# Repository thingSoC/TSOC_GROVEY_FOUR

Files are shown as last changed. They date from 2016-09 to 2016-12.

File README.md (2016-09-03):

# TSOC_GROVEY_FOUR

The **TSOC_GROVEY_FOUR** allows you to connect [thingSoC](http://thingsoc.github.io/), [Mikrobus](http://www.mikroe.com/mikrobus/), 
and/or [Grove System](http://www.seeedstudio.com/blog/2016/03/09/tutorial-intro-to-grove-connectors-for-arduinoraspberry-pi-projects/) 
Modules all at the same time, either standalone, or with any Processor or Radio module.
This gives you maximum flexiblity for parts selection and reuse. 

The **TSOC_GROVEY_FOUR** uses a Cypress Semiconductor PsoC4, a CY8C4245PVI-482 model in a 28 pin TSSOP package, for easy hand soldering.

The thingSoC "Grovey Series" was designed as "Everyday Electronics", a no-frills, low cost, approach to modular embedded product design.
thingSoC boards are similar in size to most break-out-boards (BOBs), but feature a standardized stacking pinout, as well as an I2C metadata store (EEPROM)
to indicate what peripherals are installed.

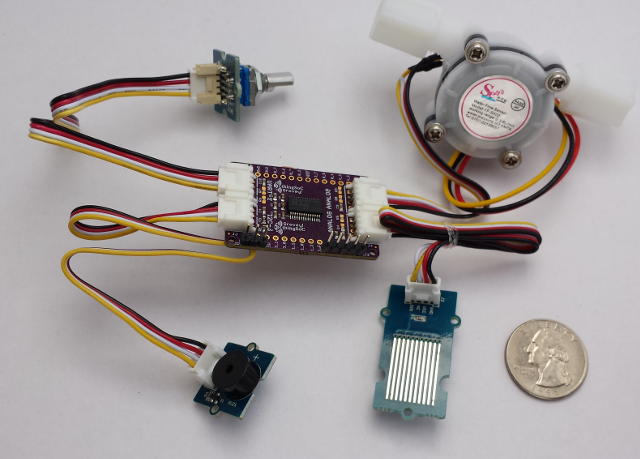
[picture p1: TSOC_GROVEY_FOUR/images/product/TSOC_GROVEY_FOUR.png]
thingSoC TSOC_GROVEY_FOUR
[TSOC_GROVEY_FOUR](https://github.com/thingSoC/TSOC_GROVEY_FOUR)

**thingSoC Reference Designs** are example thingSoC implementations that implement
various reference and testing circuits for demonstrating the use of the thingSoC libraries.
These reference designs can serve as starting templates for user designs.

---------------------------------------

## TSOC_GROVEY_FOUR Grove Application Pictures

Add the thingSoC GROVEY_WIFI for wireless measurement and control. This example uses a knob (potentiometer) for input, a water level sensor, a buzzer,  and a pump.
If the system detects water in the basement, it can sound the buzzer and start the pump (as an example...) 

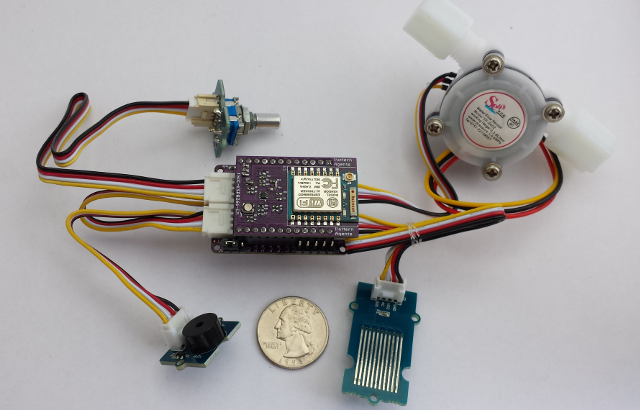
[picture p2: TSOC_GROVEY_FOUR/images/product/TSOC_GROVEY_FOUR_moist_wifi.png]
thingSoC TSOC_GROVEY_FOUR
[*TSOC_GROVEY_FOUR*](https://github.com/thingSoC/TSOC_GROVEY_FOUR)

Or use a soil moisture sensor to control when your plants get watered. Add an OLED display to get you measusements.

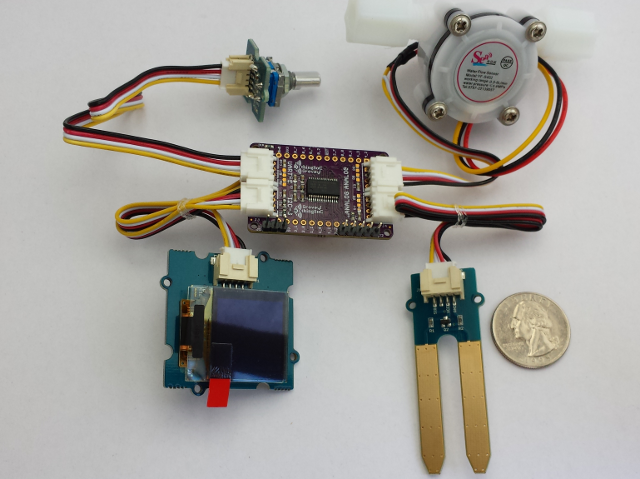
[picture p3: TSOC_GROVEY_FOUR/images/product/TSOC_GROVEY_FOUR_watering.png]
thingSoC TSOC_GROVEY_FOUR
[*TSOC_GROVEY_FOUR*](https://github.com/thingSoC/TSOC_GROVEY_FOUR)

---------------------------------------

## TSOC_GROVEY_FOUR Mikrobus "Click" Application Pictures

The **TSOC_GROVEY_FOUR** is also compatibile with most [Mikrobus](http://www.mikroe.com/mikrobus/) "Click" peripherals.
now you can mix-and-match Click System peripherals with Grove System peripherals at the same time!

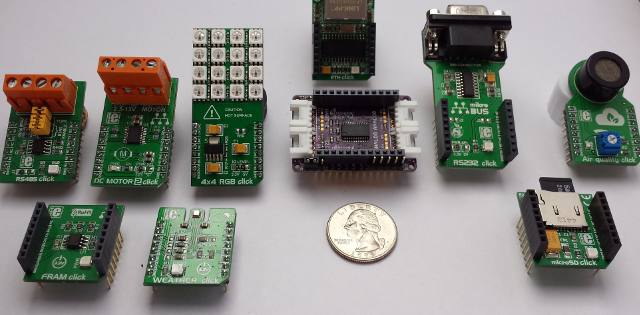
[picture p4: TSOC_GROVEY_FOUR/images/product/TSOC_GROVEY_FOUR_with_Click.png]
thingSoC TSOC_GROVEY_FOUR
[*TSOC_GROVEY_FOUR*](https://github.com/thingSoC/TSOC_GROVEY_FOUR)

---------------------------------------

## TSOC_GROVEY_FOUR Arduino Sketch Examples

Under the "examples" directory are several Arduino IDE examples for using the TSOC_GROVEY_FOUR board with Arduino IDE.
Using the Arduino "Wire" library for I2C communications, or Arduino "Serial" library for UART communications,
it is simple to control the TSOC_GROVEY_FOUR. Although the TSOC_GROVEY_FOUR uses programmable hardware, the device comes
preprogrammed to act as either an I2C I/O Expander, or a UART command line controlled peripheral. T

```c
 
 coming...

```

---------------------------------------
## TSOC_GROVEY_FOUR Programming

The included UART bootloader allows you to reprogram the PSoC with your own programs,
or to chose from a variety of "recipe" programs available for many applications.

You can reprogram the board using any FTDI USB to UART, or any Grove UART adapter :

In order to reprogram the Cypress PSoC4 device, you will need to download and install the PSoC Creator tool, which includes a serial bootloader host application.

Select Tools -> Bootloader Host 

Then select the hex (cyacd) file that you wish to program, and the COM: port of your device. Proess the "Upload" button to reflash teh device.

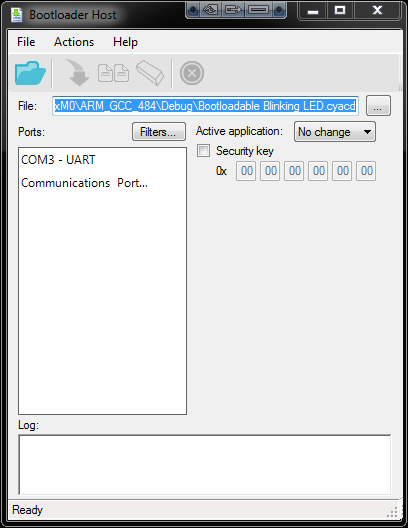
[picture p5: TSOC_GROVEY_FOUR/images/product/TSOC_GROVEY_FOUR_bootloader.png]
thingSoC TSOC_GROVEY_FOUR
[PSoC Creator Bootloader Host](https://github.com/thingSoC/TSOC_GROVEY_FOUR)

---------------------------------------
## Other Applications

The TSOC_GROVEY_FOUR can also drive other devices, such as Servos, Motors, Relays and more.

---------------------------------------

## TSOC_GROVEY_FOUR Status <a name="TSOC_GROVEY_FOUR_status"/>

**08/15/2016:** 
Revision 1.4 - Initial Layout 

**08/20/2016:**
Revision 2.0 - Alpha version

**09/02/2016:**
Revision 3.0 - (WIP) add FTDI, JTAG, and 3.3V/5V voltage select jumper

---------------------------------------
## TSOC_GROVEY_FOUR Model Images

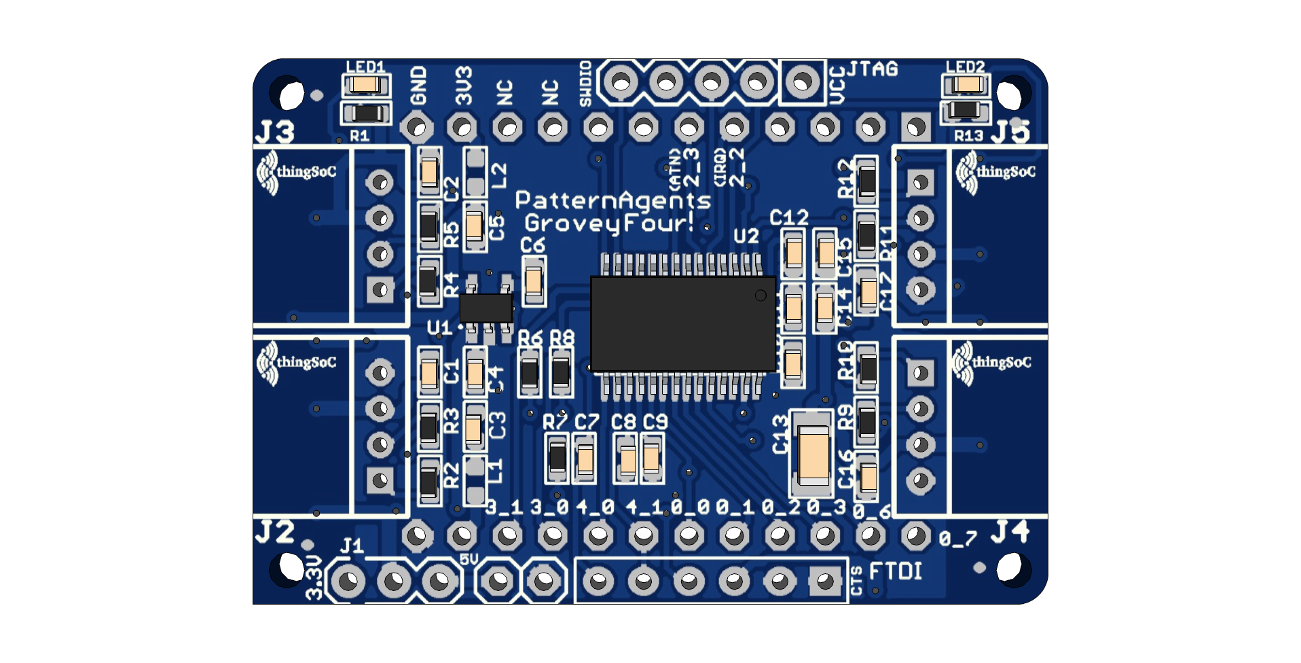
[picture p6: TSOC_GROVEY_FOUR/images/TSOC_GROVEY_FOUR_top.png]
thingSoC TSOC_GROVEY_FOUR
[TSOC_GROVEY_FOUR](https://github.com/thingSoC/TSOC_GROVEY_FOUR)

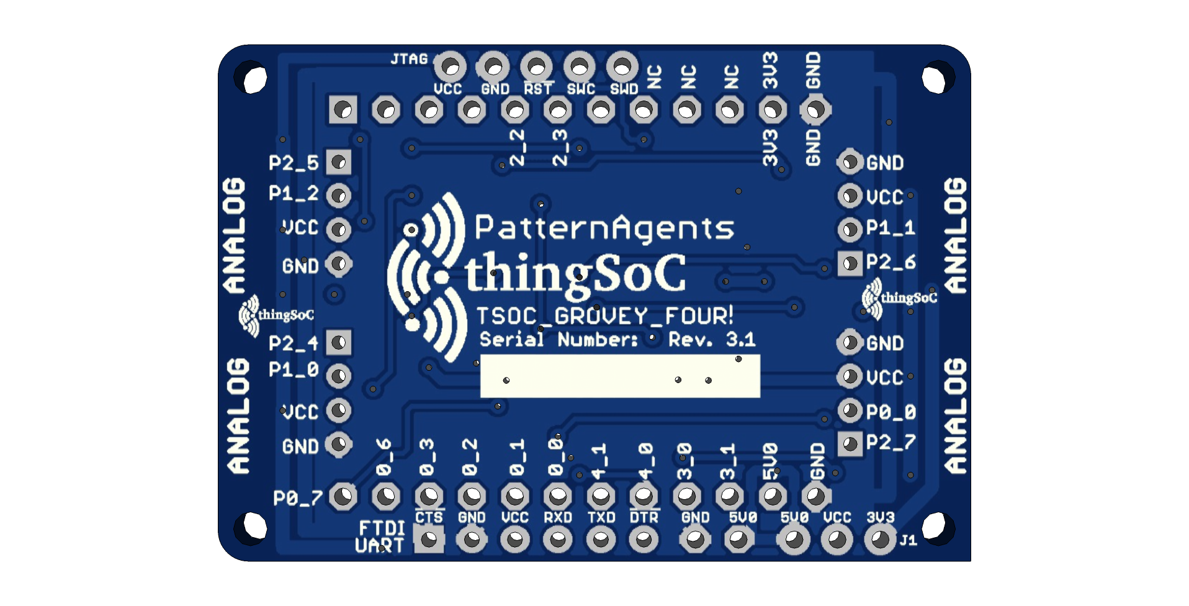
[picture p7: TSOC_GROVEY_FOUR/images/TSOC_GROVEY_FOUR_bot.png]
thingSoC TSOC_GROVEY_FOUR
[TSOC_GROVEY_FOUR](https://github.com/thingSoC/TSOC_GROVEY_FOUR)

---------------------------------------

## TSOC_GROVEY_FOUR Documentation Index <a name="TSOC_GROVEY_FOUR_documentation_index"/>

[TSOC_GROVEY_FOUR Project](http://thingsoc.github.io/projects/TSOC_GROVEY_FOUR.html)

[TSOC_GROVEY_FOUR Hardware](https://github.com/thingSoC/TSOC_GROVEY_FOUR/tree/master/TSOC_GROVEY_FOUR/hardware)

---------------------------------------

## thingSoC Documentation Index <a name="thingSoC_documentation_index"/>

[thingSoC Organization Website](http://thingSoC.github.io)

[thingSoC FAQ - Frequently Asked Questions](http://thingsoc.github.io/support/faq.html)

---------------------------------------

[thingSoC 
*thingSoC*](http://thingsoc.github.io)

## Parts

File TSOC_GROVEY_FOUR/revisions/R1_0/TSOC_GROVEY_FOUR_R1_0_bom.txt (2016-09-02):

Partlist exported from U:/PatternAgents/eagle/TSOC_Modules/TSOC_GROVEY/TSOC_GROVEY/TSOC_GROVEY.sch at 8/27/2016 3:07:50 PM  Revision 2.0                                                                                  

Qty Value             Device                          Package           Parts                       Description 
1   JMP               JMP-2-PTH                       JMP-2-PTH-2.54    J1                          Jumper
1   Red               LED0603                         LED-0603          D1                          LEDs
3   0.1uF             CAP0603-CAP                     0603-CAP          C3, C6, C8                  Capacitor
1   10K               RESISTOR_SFE0603-RES            0603-RES          R2                          Resistor
1   1K                RESISTOR_SFE0603-RES            0603-RES          R10                         Resistor                                                                  
7   1uF               CAP0603-CAP                     0603-CAP          C1, C2, C4, C5, C7, C9, C10 Capacitor
6   2k2               RESISTOR0603-RES                0603-RES          R1, R3, R4, R5, R8, R9      Resistor                                                                  
4   4P-2.0-90D        GROVE-CONNECTOR-DIP-90D(4P-2.0) HW4-2.0-90D       J3, J4, J5, J6              320110034
1   CY8C4245PVI-482   CY8C4245PVI-482                 SSOP28            U1                          Cypress PSoC® 4
2   DNP               RESISTOR0603-RES                0603-RES          R6, R7                      Resistor                                                                  
1   JTAG-ISSPMIN      JTAG-ISSPMIN                    PSOC_JTAG_MINSILK J2                          JTAG-ISSP Connector

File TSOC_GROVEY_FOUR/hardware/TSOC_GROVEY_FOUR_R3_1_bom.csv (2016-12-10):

Qty | Value | Device | Package | Parts | Description
1 | 3.3V | V_REG_AP2112K-3.3V | SOT23-5 | U1 | AP2112 - 600mA CMOS LDO Regulator w/ Enable
1 | CY8C4XXX-28 | CY8C4XXX-28 | SSOP28 | U2 | Cypress PSoC® 4 - Programmable System on Chip, Cortex-M0 Based
1 | YELLOW-0603 | SMD-LED-CLEAR-YELLOW(0603) | LED-0603 | LED2 | 304090044
1 | GREEN-0603 | SMD-LED-CLEAR-GREEN(0603) | LED-0603 | LED1 | 304090043
2 | 120OHM-500MA | SMD-FERRITE-CHIP-120-OHM-500MA(0603) | L0603 | L1, L2 | 303030001
10 | 1K 1/10W | SMD-RES-1K-5%-1/10W(0603) | R0603 | R1, R2, R3, R4, R5, R9, R10, R11, R12, R13 | 301010291
3 | 10K 1/10W | SMD-RES-10K-5%-1/10W(0603) | R0603 | R6, R7, R8 | 301010293
1 | 2.2nf | CERAMIC-1NF-50V-5%-C0G(0603) | C0603 | C8 | 302010341
1 | 10nf | CERAMIC-10NF-50V-10%-X7R(0603) | C0603 | C9 | 302010140
9 | 100nf | CERAMIC-100NF-50V-10%-X7R(0603) | C0603 | C1, C2, C4, C6, C7, C11, C15, C16, C17 | 302010138
3 | 1uF | CERAMIC-100NF-50V-10%-X7R(0603) | C0603 | C10, C12, C14 | 302010138
2 | 10uf | CERAMIC-10UF-10V-10%-X5R(0603) | C0603 | C3, C5 | 302010103
1 | 47uf | CERAMIC-47UF-6.3V-20%-X5R(1206) | C1206 | C13 | 302010183
4 | 4P-2.0-90D | GROVE-CONNECTOR-DIP-90D(4P-2.0) | HW4-2.0-90D | J2, J3, J4, J5 | 320110034
1 | 6p-2.54 | DIP-BLACK-MALE-HEADER(6P-2.54) | H6-2.54 | FTDI | 320020078
1 |  | M02PTH | 1X02 | 5V0, GND | Header 2 Pin Male
1 | JTAG-ISSPMIN | JTAG-ISSPMIN | PSOC_JTAG_MINSILK | JTAG | JTAG-ISSP Programming Connector
1 | NO | JMP-3-NO-PTH | JMP-3-NO-PTH-2.54 | J1 | Three Terminal Jumper - Normally Open
1 | TSOC-PCB-SINGLE | TSOC-PCB-SINGLE | TSOC-BB-BRD-DIM | $$U$1 | thingSoC PCB Outlines

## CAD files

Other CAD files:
TSOC_GROVEY_FOUR/eagleUp/TSOC_GROVEY_FOUR.skp

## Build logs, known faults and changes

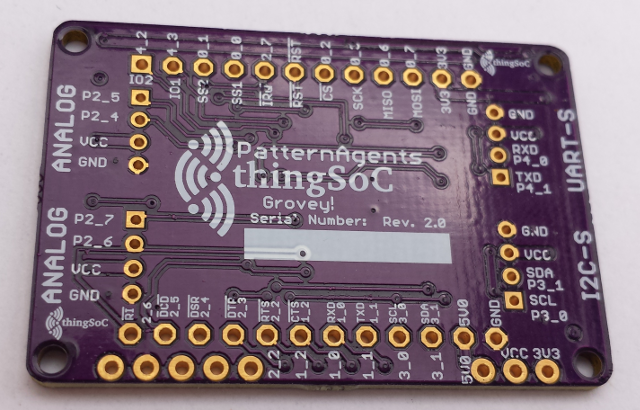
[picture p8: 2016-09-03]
TSOC_GROVEY_FOUR/revisions/R3_0/images/product/TSOC_GROVEY_FOUR_pcb_bot.png

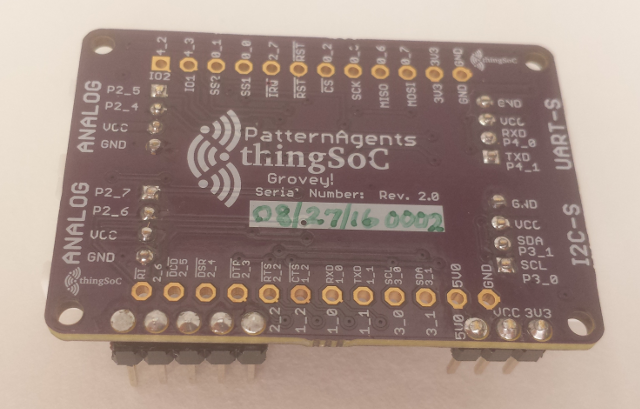
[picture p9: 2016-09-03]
TSOC_GROVEY_FOUR/revisions/R3_0/images/product/TSOC_GROVEY_FOUR_bot.png

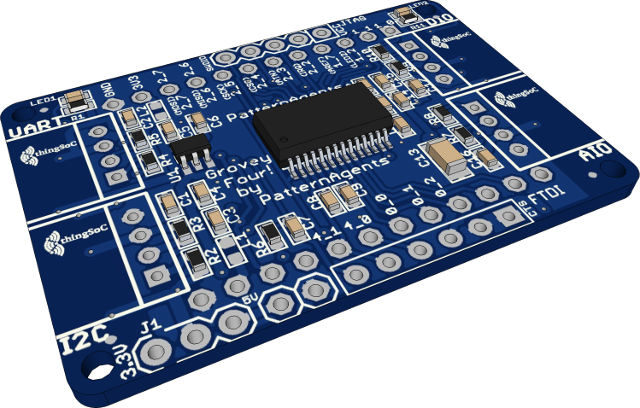
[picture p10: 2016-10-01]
TSOC_GROVEY_FOUR/revisions/R3_0/images/TSOC_GROVEY_FOUR_iso.png

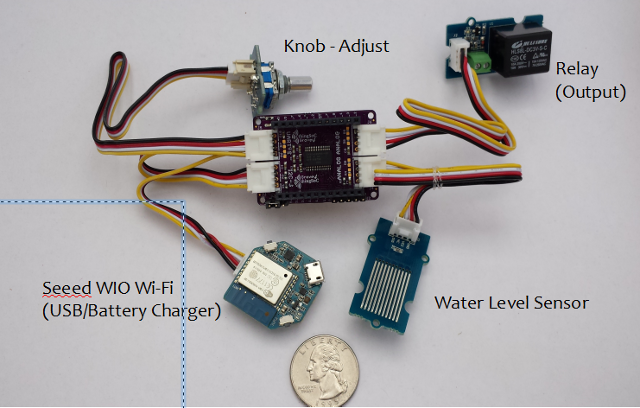
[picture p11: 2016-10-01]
TSOC_GROVEY_FOUR/revisions/R1_0/images/product/TSOC_GROVEY_FOUR_WIO.png

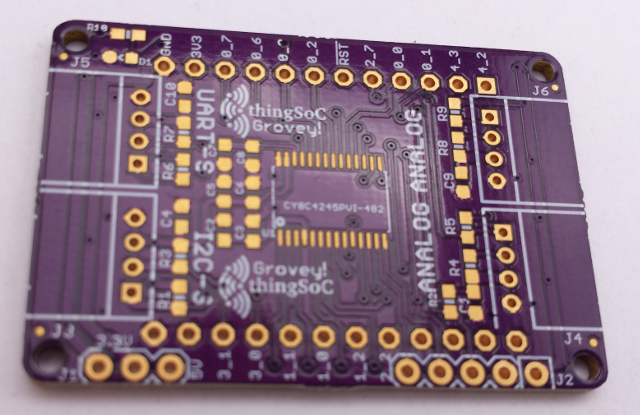
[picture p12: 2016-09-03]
TSOC_GROVEY_FOUR/revisions/R3_0/images/product/TSOC_GROVEY_FOUR_pcb_top.png

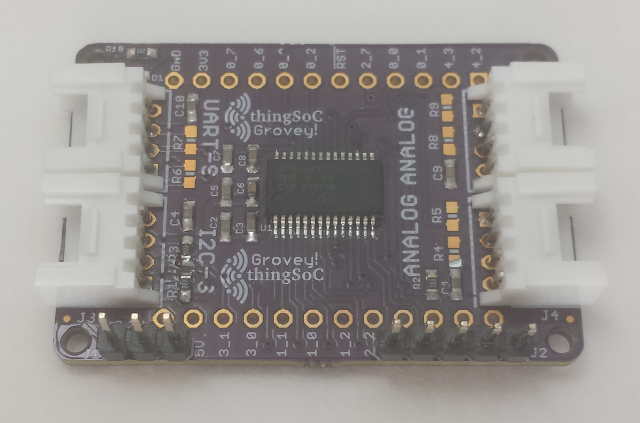
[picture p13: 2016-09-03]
TSOC_GROVEY_FOUR/revisions/R1_0/images/product/TSOC_GROVEY_FOUR_top.png

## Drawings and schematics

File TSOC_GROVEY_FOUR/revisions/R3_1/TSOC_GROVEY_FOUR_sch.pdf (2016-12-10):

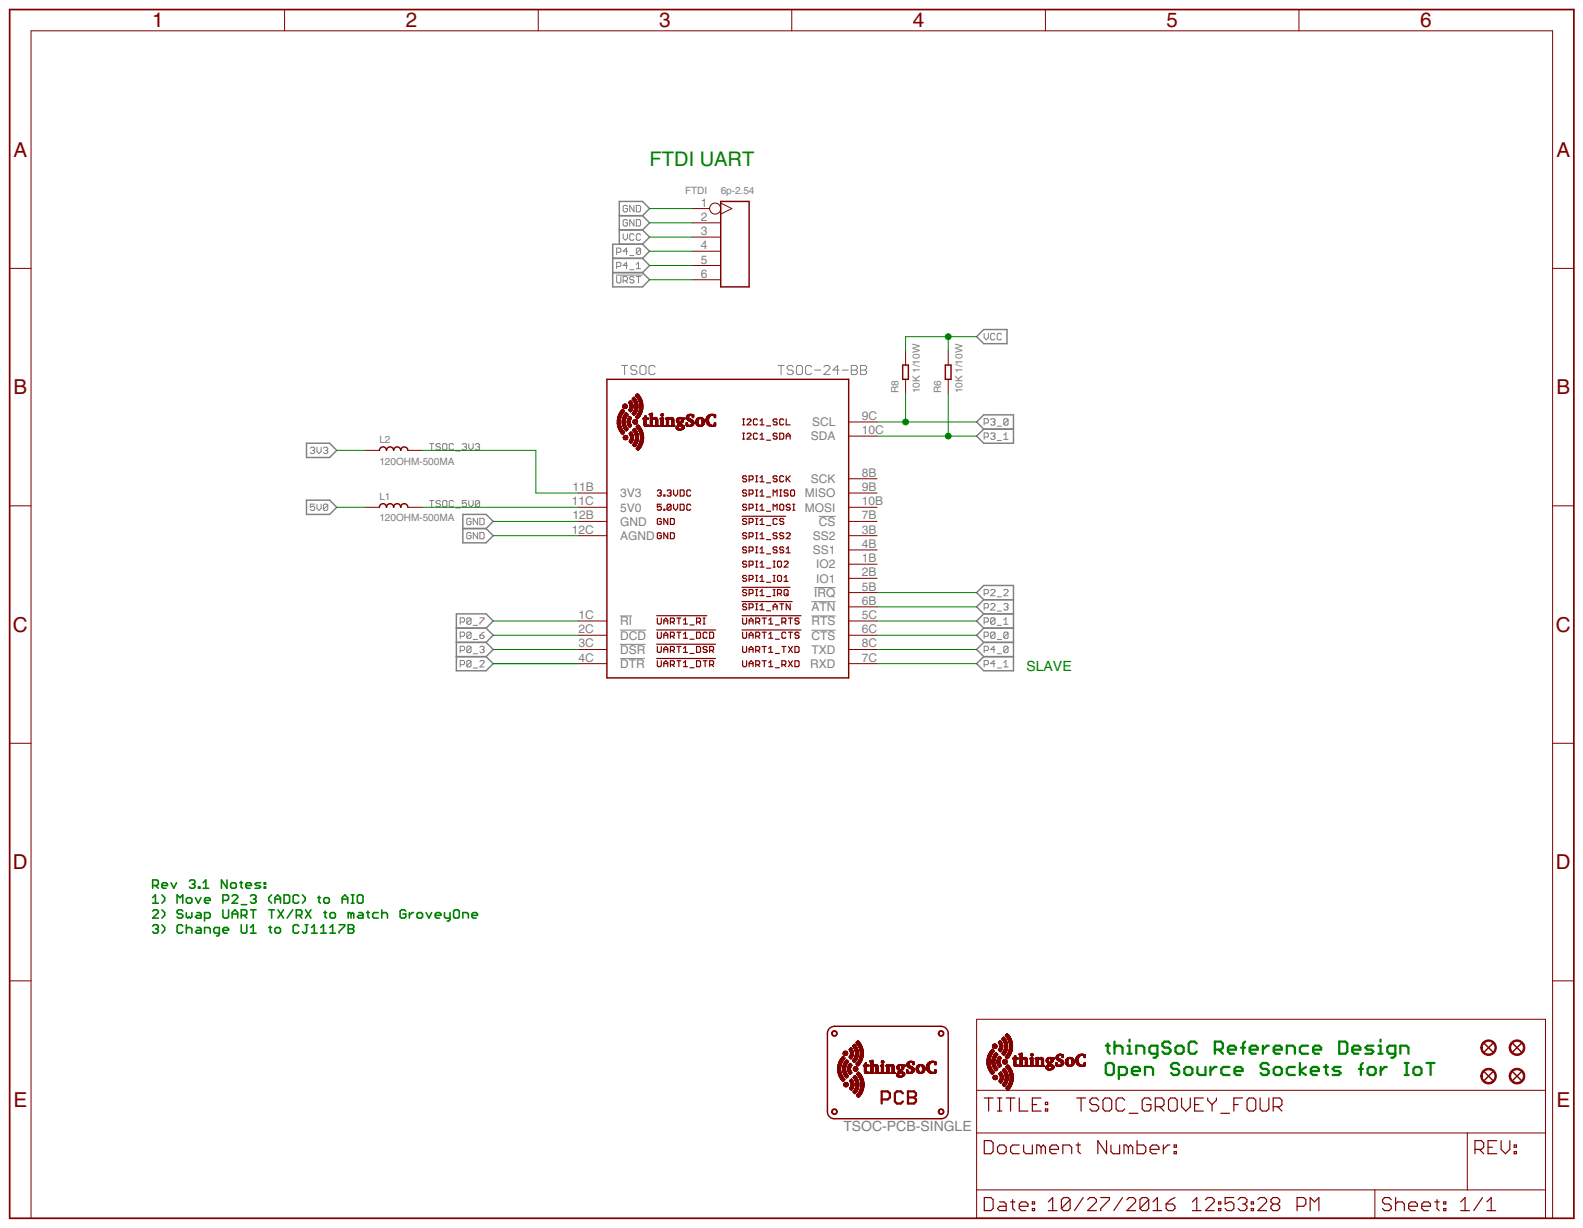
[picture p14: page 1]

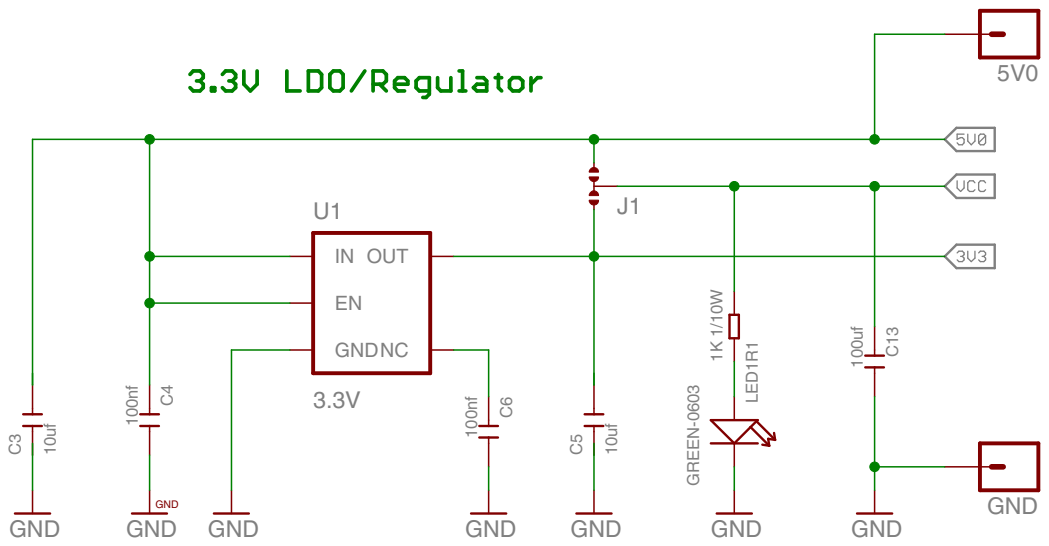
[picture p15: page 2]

100nf GND GND GND GND

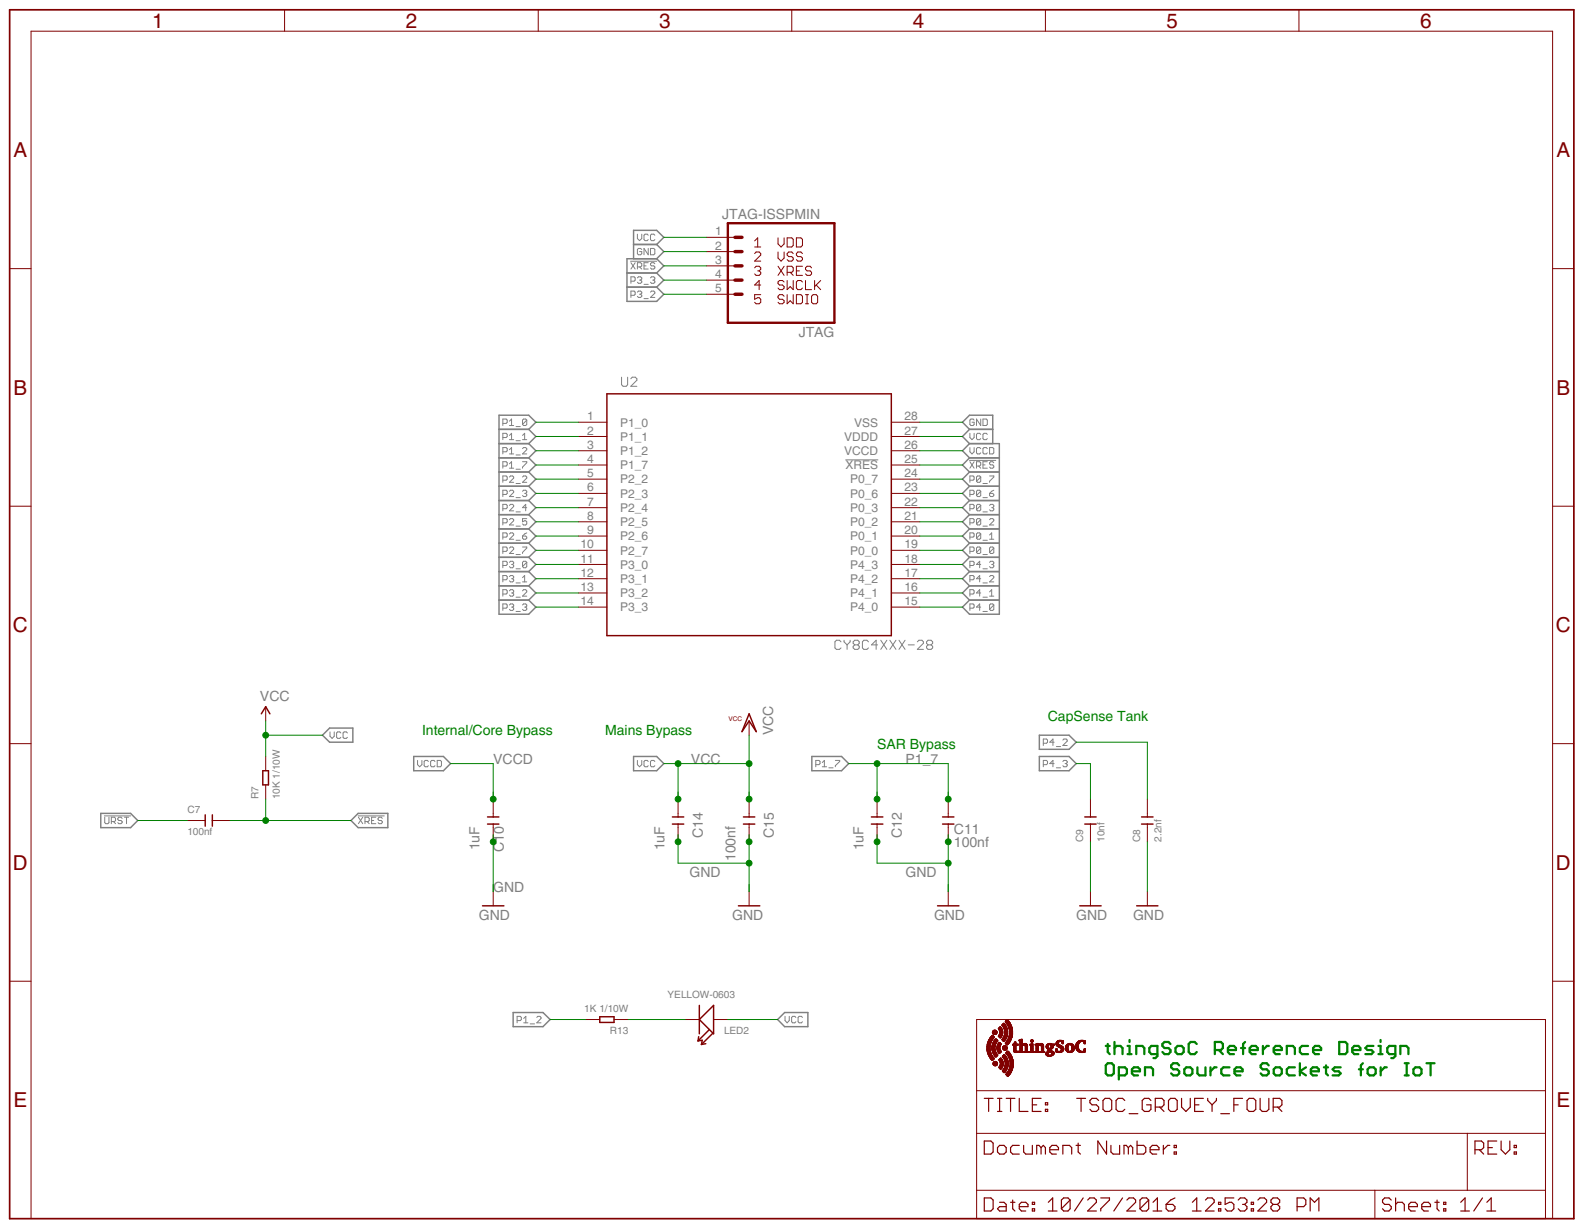
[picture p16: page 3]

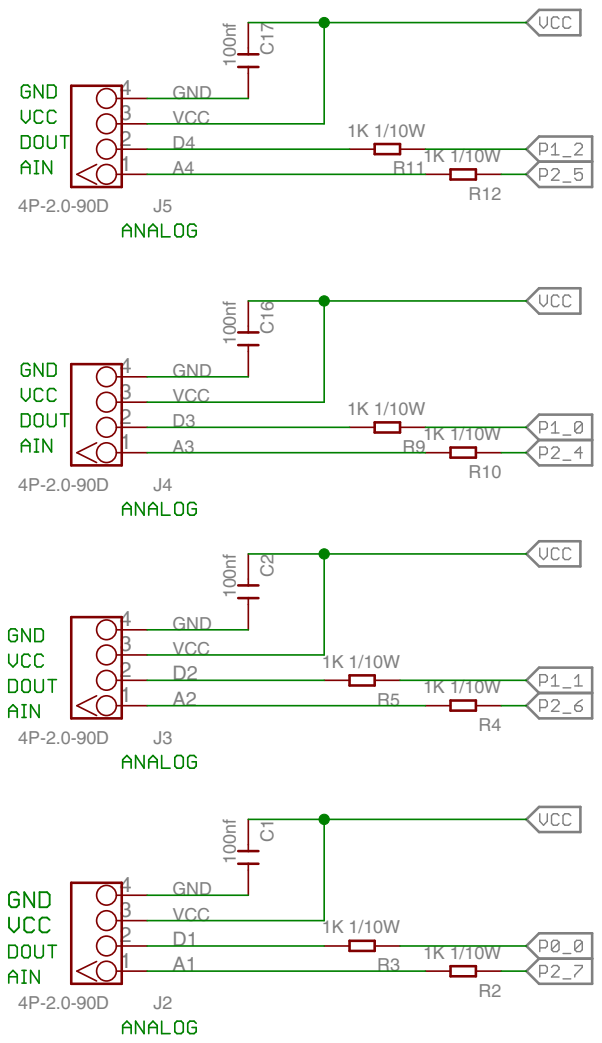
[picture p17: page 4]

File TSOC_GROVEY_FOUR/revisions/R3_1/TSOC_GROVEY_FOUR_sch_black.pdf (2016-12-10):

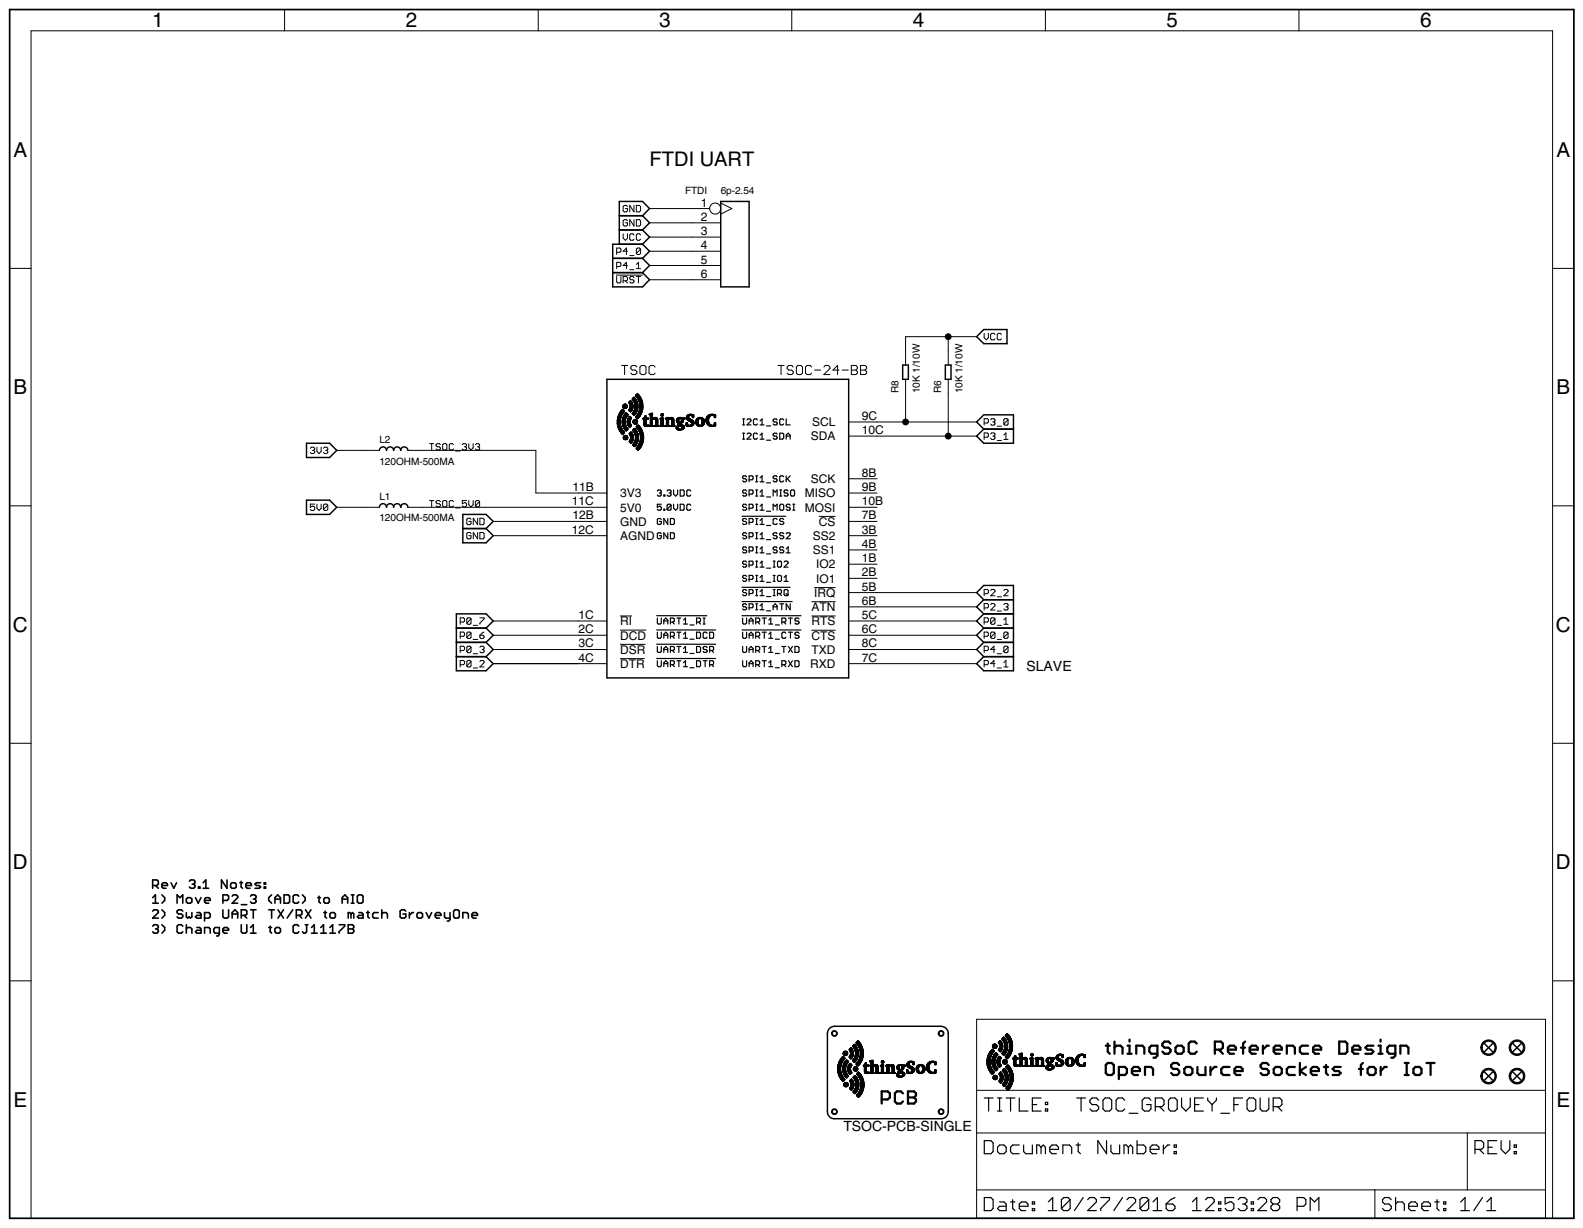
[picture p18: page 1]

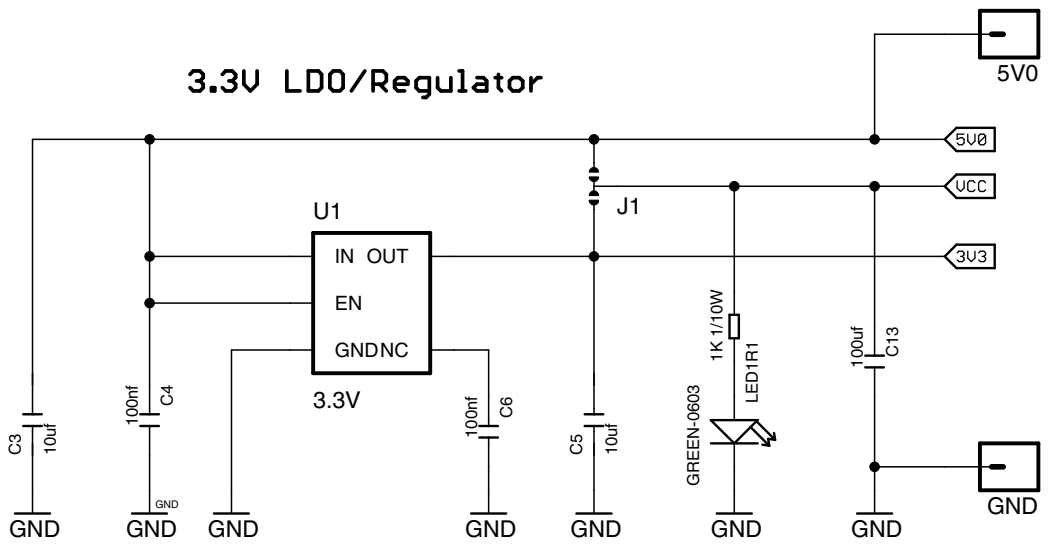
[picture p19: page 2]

100nf GND GND GND GND

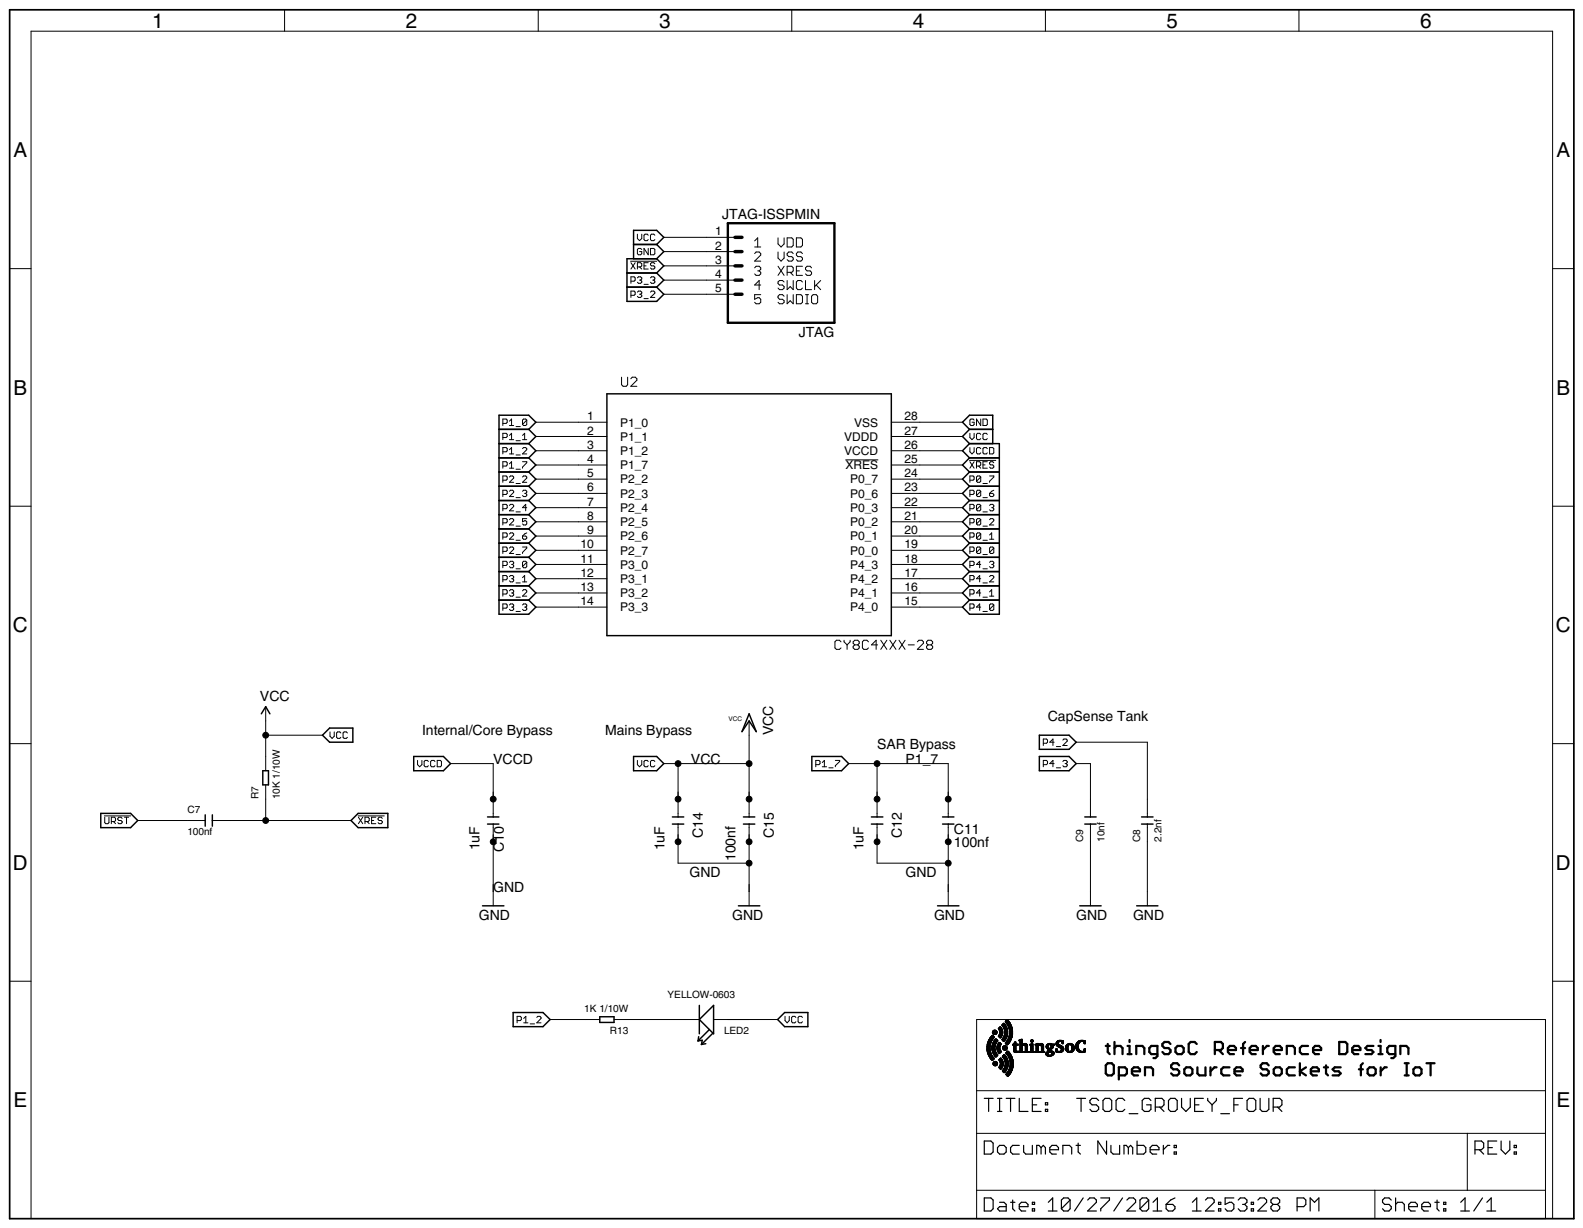
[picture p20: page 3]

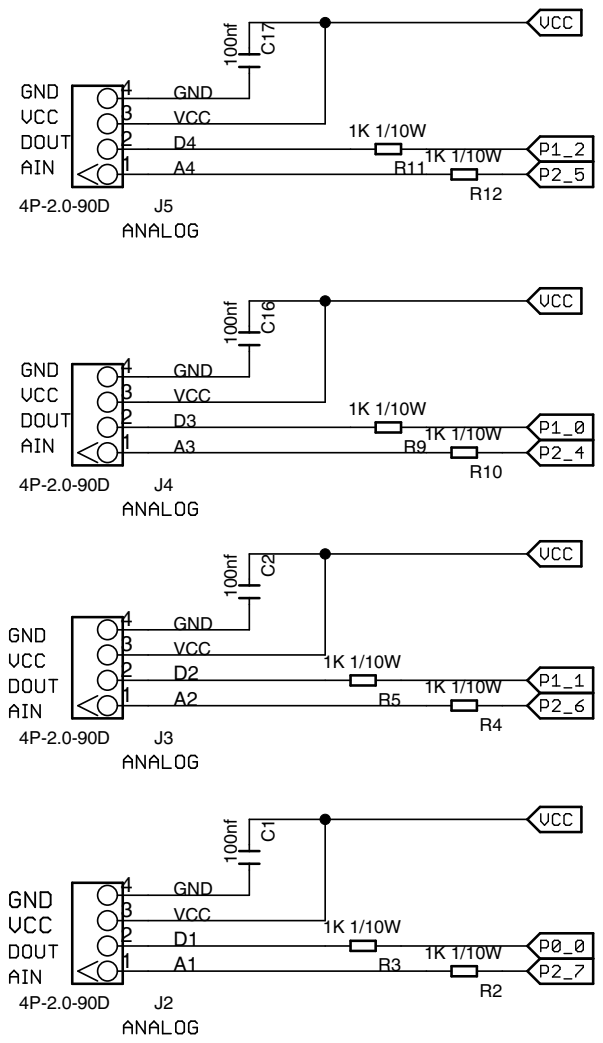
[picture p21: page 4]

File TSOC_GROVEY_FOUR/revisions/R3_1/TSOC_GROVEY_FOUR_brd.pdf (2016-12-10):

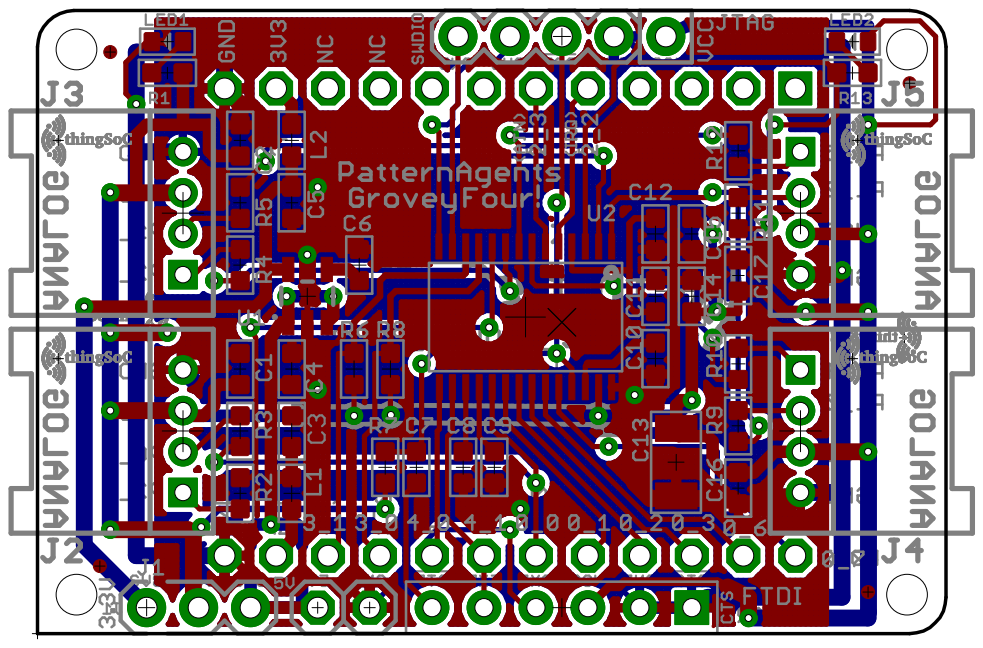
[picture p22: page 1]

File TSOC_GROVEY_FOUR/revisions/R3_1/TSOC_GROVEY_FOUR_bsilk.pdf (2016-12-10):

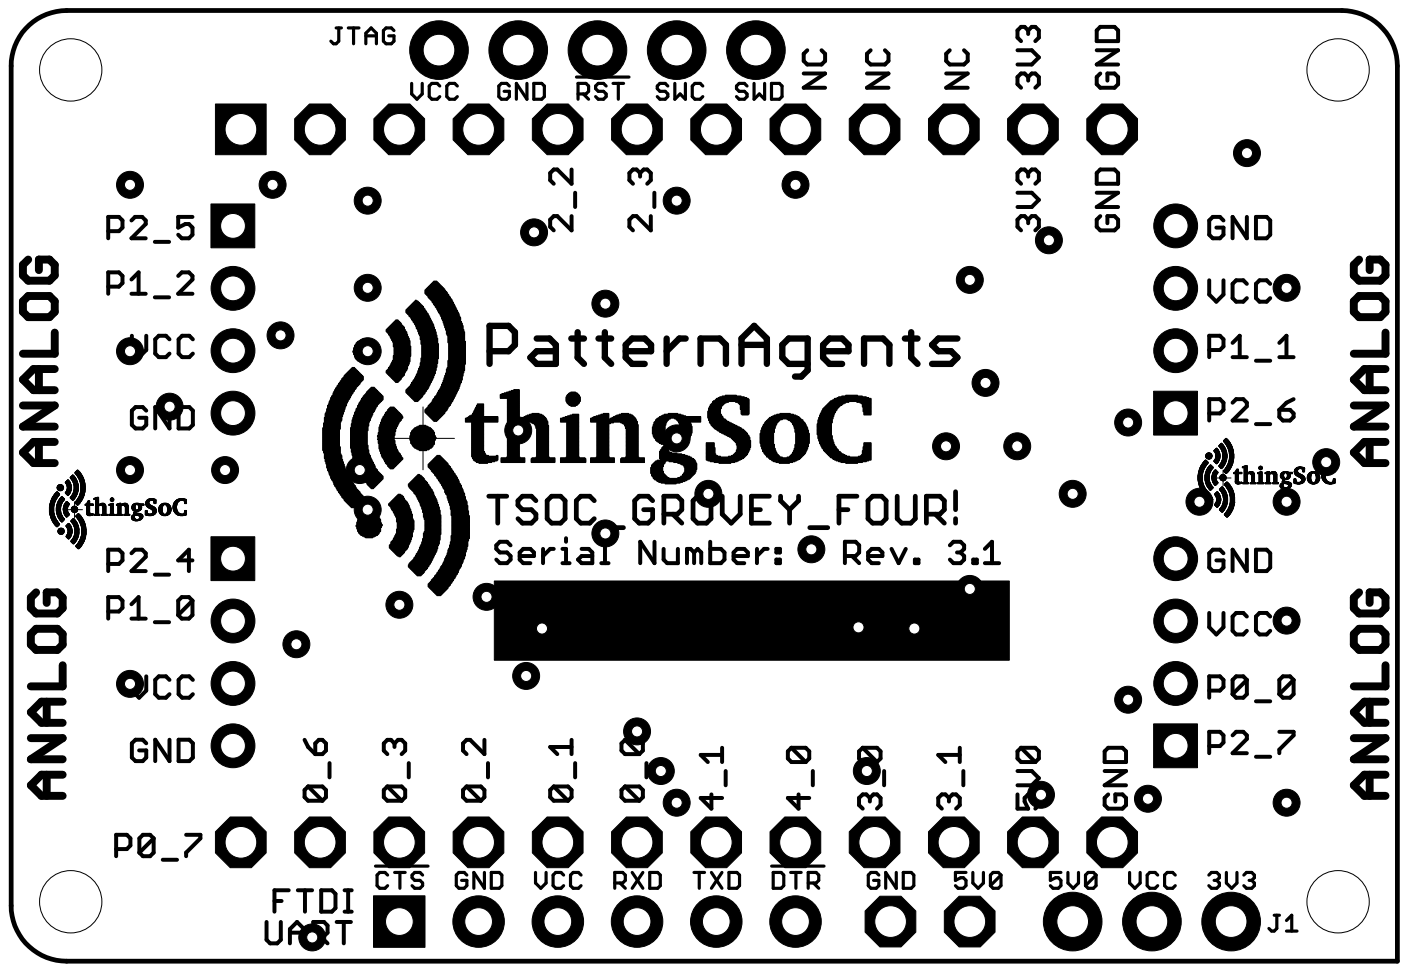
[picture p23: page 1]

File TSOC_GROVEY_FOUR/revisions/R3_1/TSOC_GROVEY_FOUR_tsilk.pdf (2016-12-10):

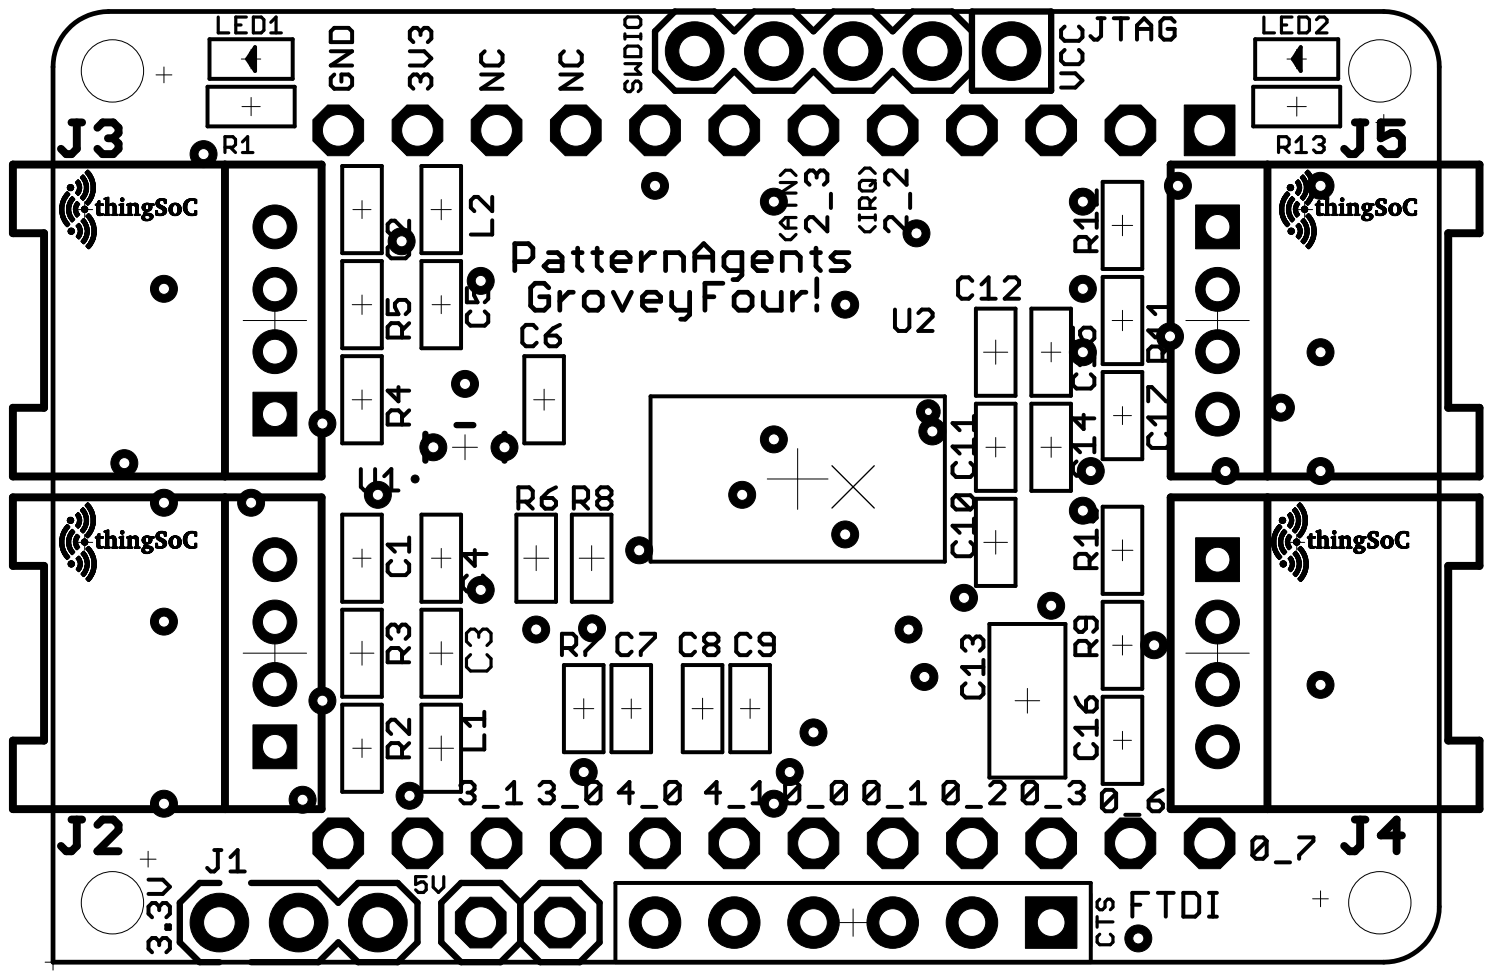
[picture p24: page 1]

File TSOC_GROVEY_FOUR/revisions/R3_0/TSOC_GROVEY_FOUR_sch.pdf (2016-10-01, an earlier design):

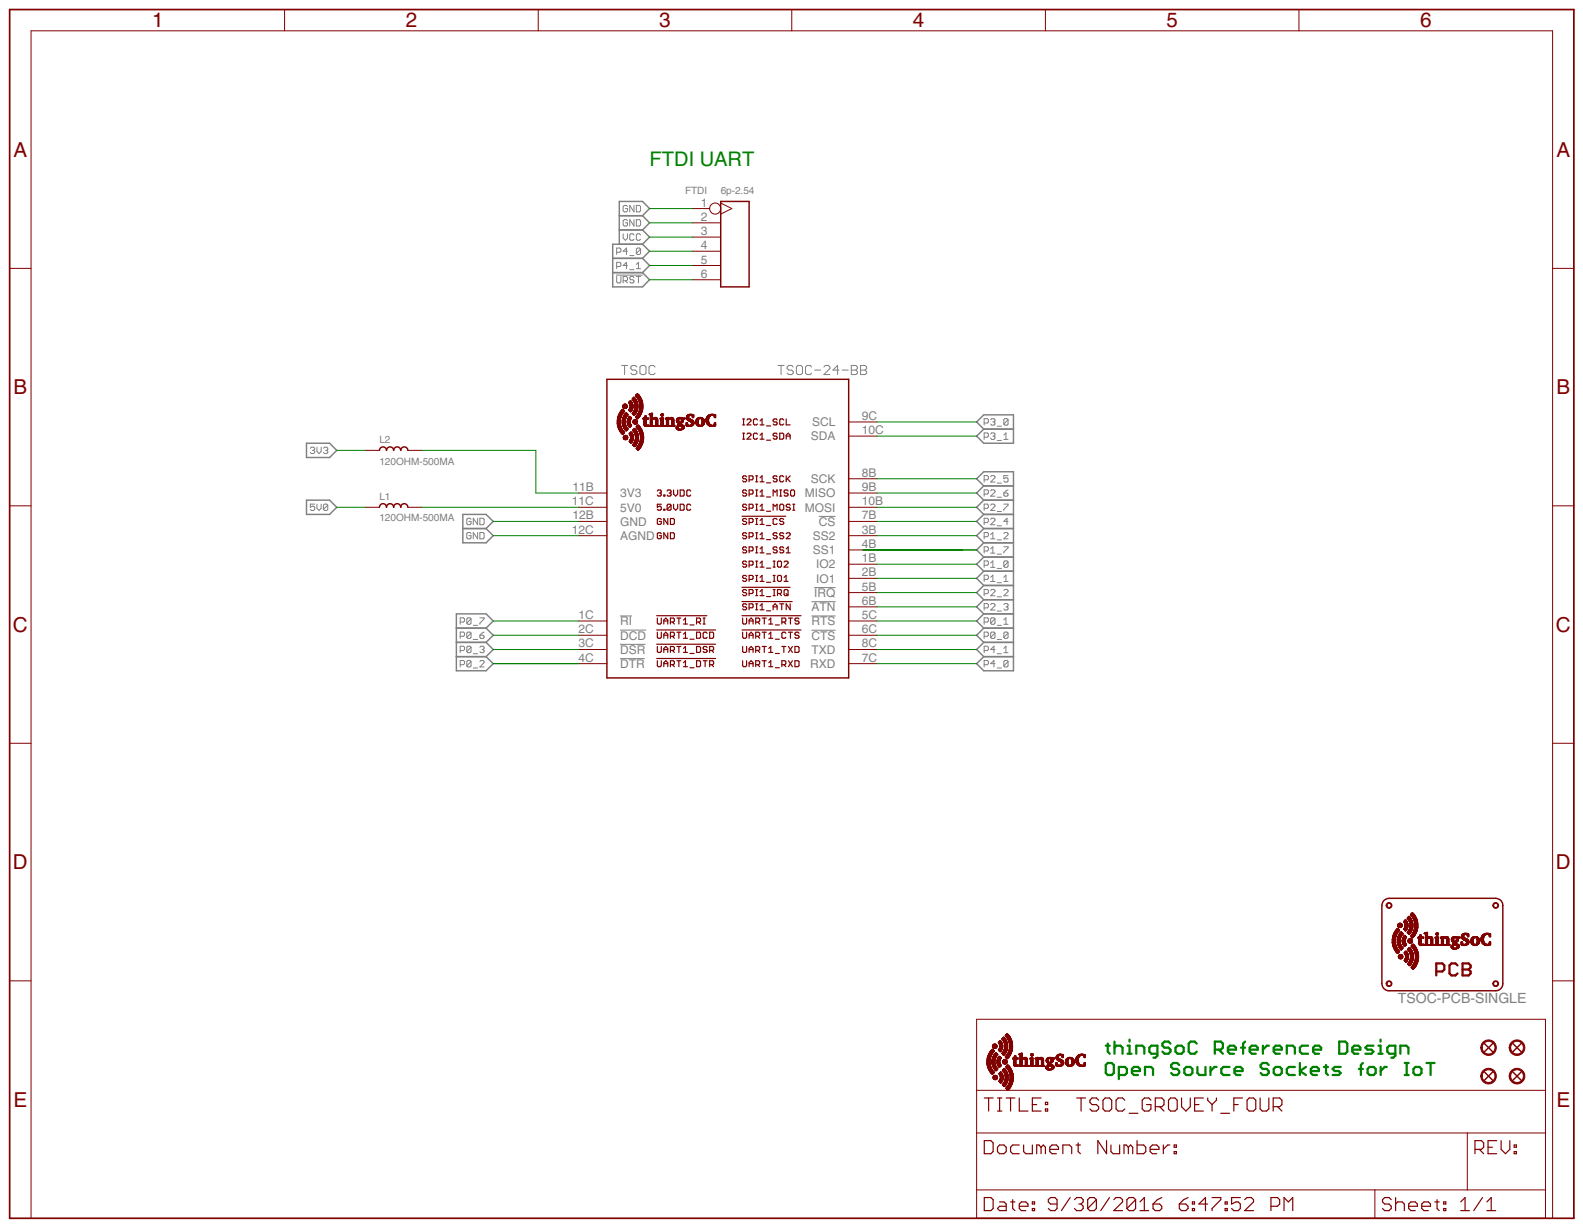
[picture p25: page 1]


100nf GND GND GND GND



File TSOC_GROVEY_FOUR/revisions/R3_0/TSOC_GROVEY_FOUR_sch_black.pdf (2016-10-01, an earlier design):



100nf GND GND GND GND






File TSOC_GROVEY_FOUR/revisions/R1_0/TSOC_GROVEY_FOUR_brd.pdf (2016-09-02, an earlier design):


8/15/2016 9:49:21 AM U:\PatternAgents\eagle\TSOC_Modules\TSOC_GROVEY\TSOC_GROVEY\hardware\TSOC_GROVEY_R2_0_gerbers\TSOC_GROVEY.brd

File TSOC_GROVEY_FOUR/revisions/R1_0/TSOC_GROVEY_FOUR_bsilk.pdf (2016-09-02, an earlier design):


8/15/2016 9:50:56 AM f=5.00 mirrored U:\PatternAgents\eagle\TSOC_Modules\TSOC_GROVEY\TSOC_GROVEY\hardware\TSOC_GROVEY_R2_0_gerbers\TSOC_GROVEY.brd

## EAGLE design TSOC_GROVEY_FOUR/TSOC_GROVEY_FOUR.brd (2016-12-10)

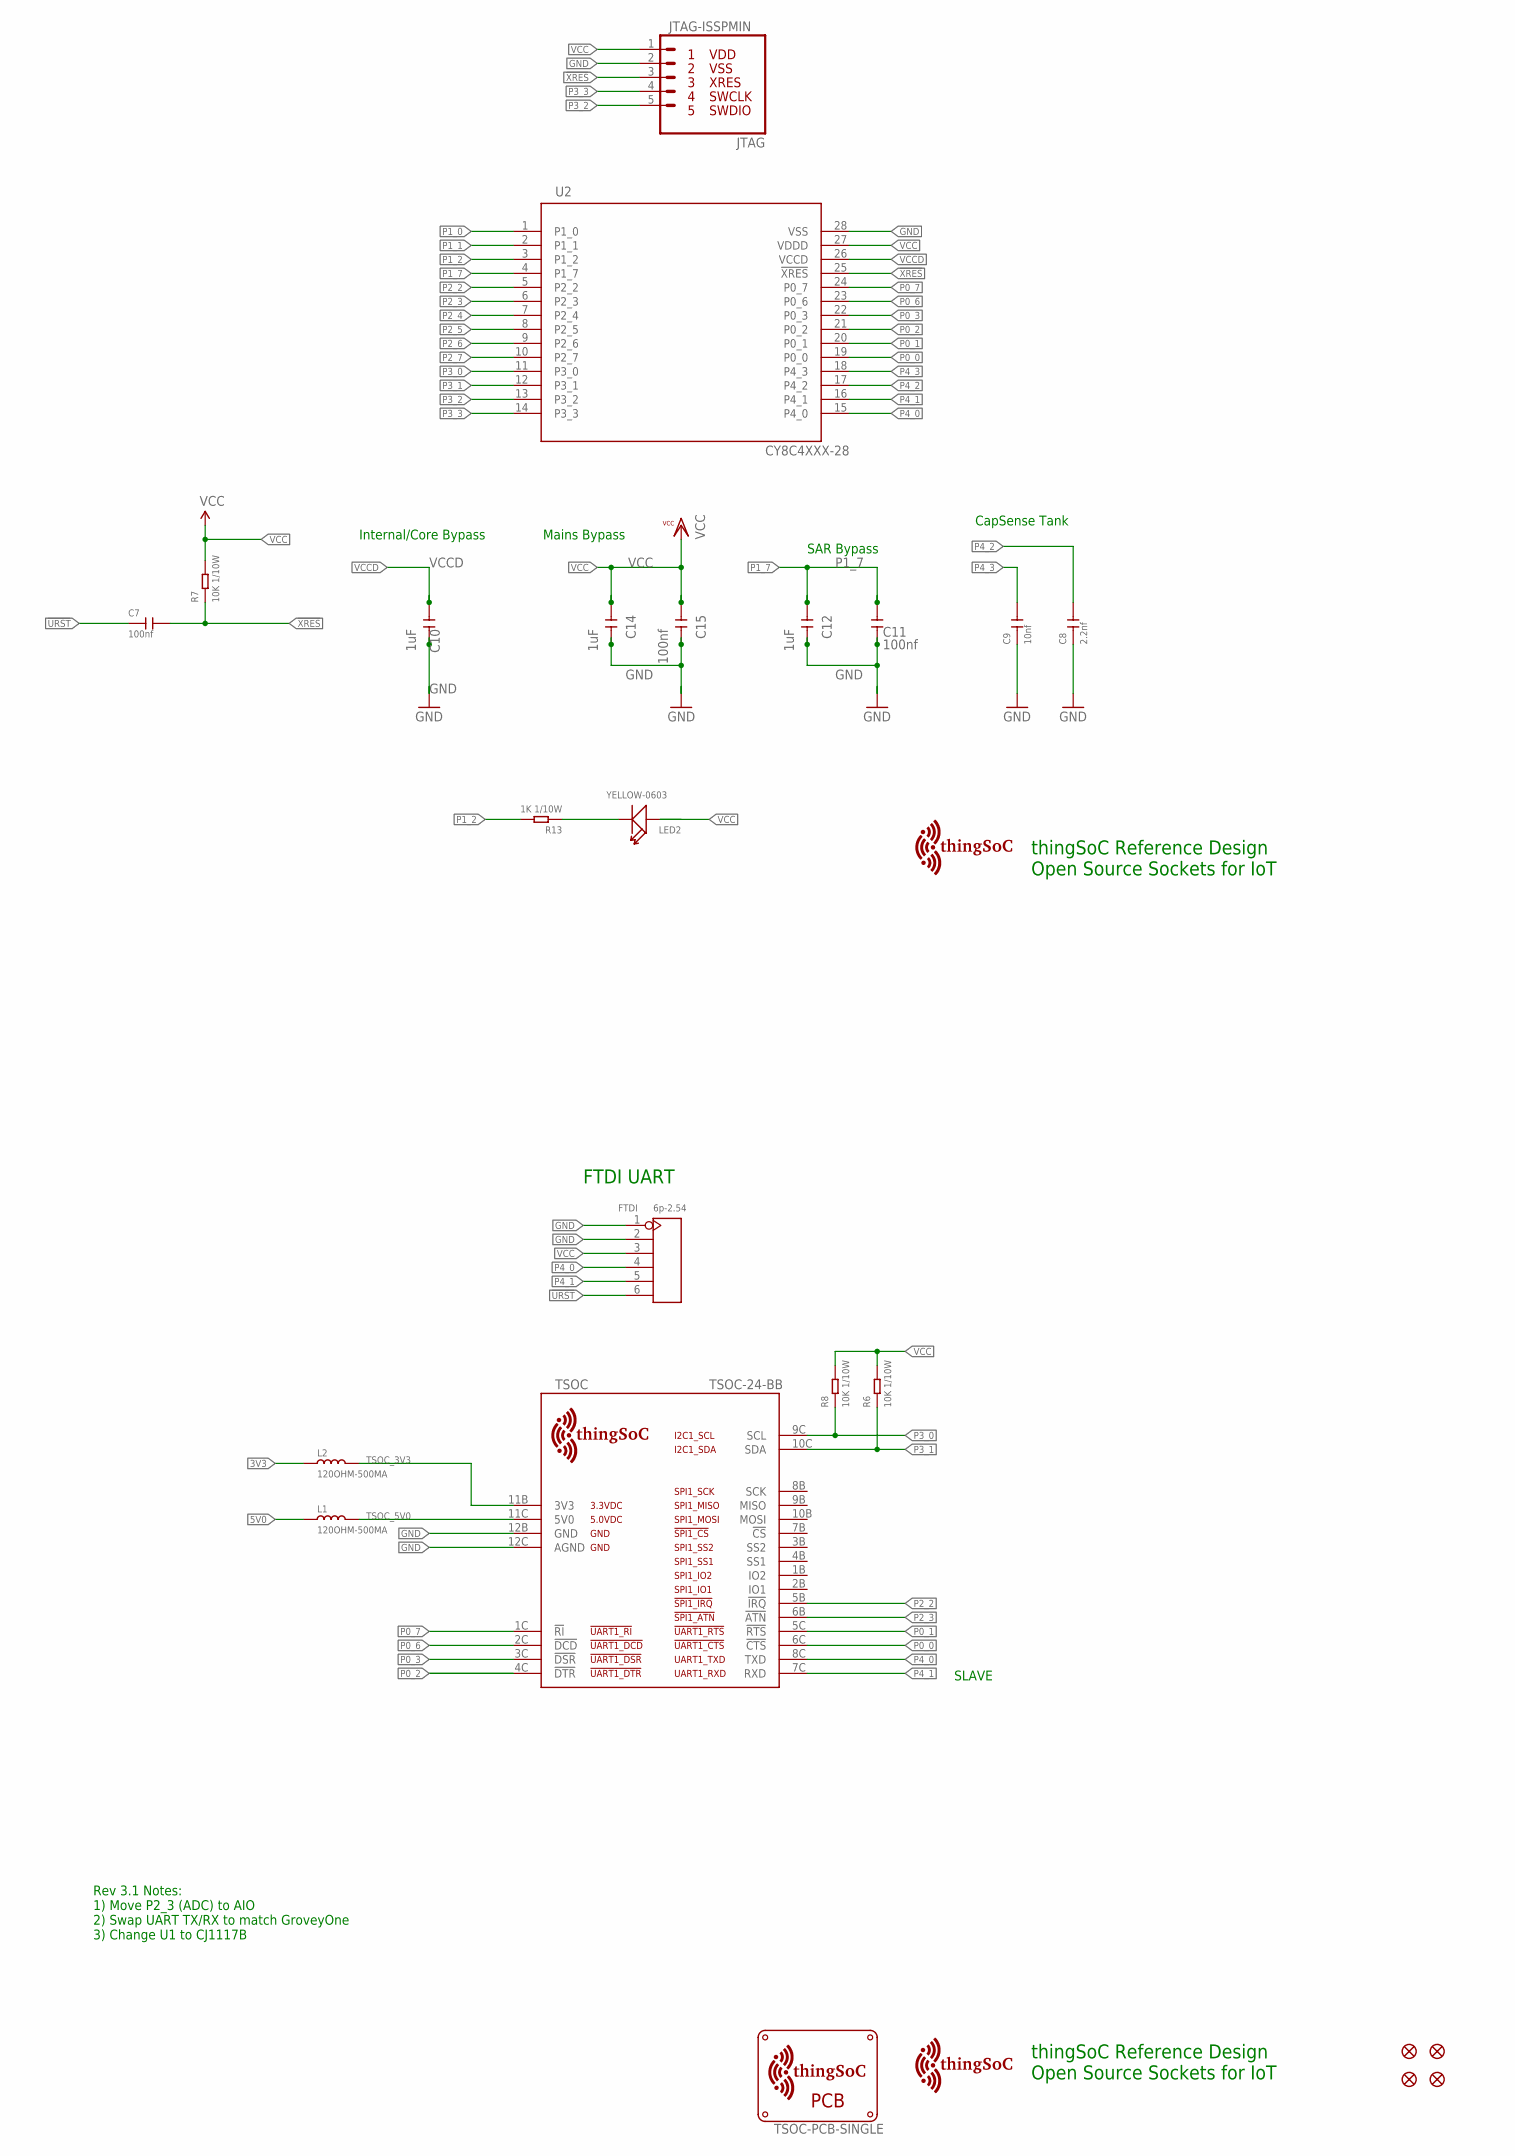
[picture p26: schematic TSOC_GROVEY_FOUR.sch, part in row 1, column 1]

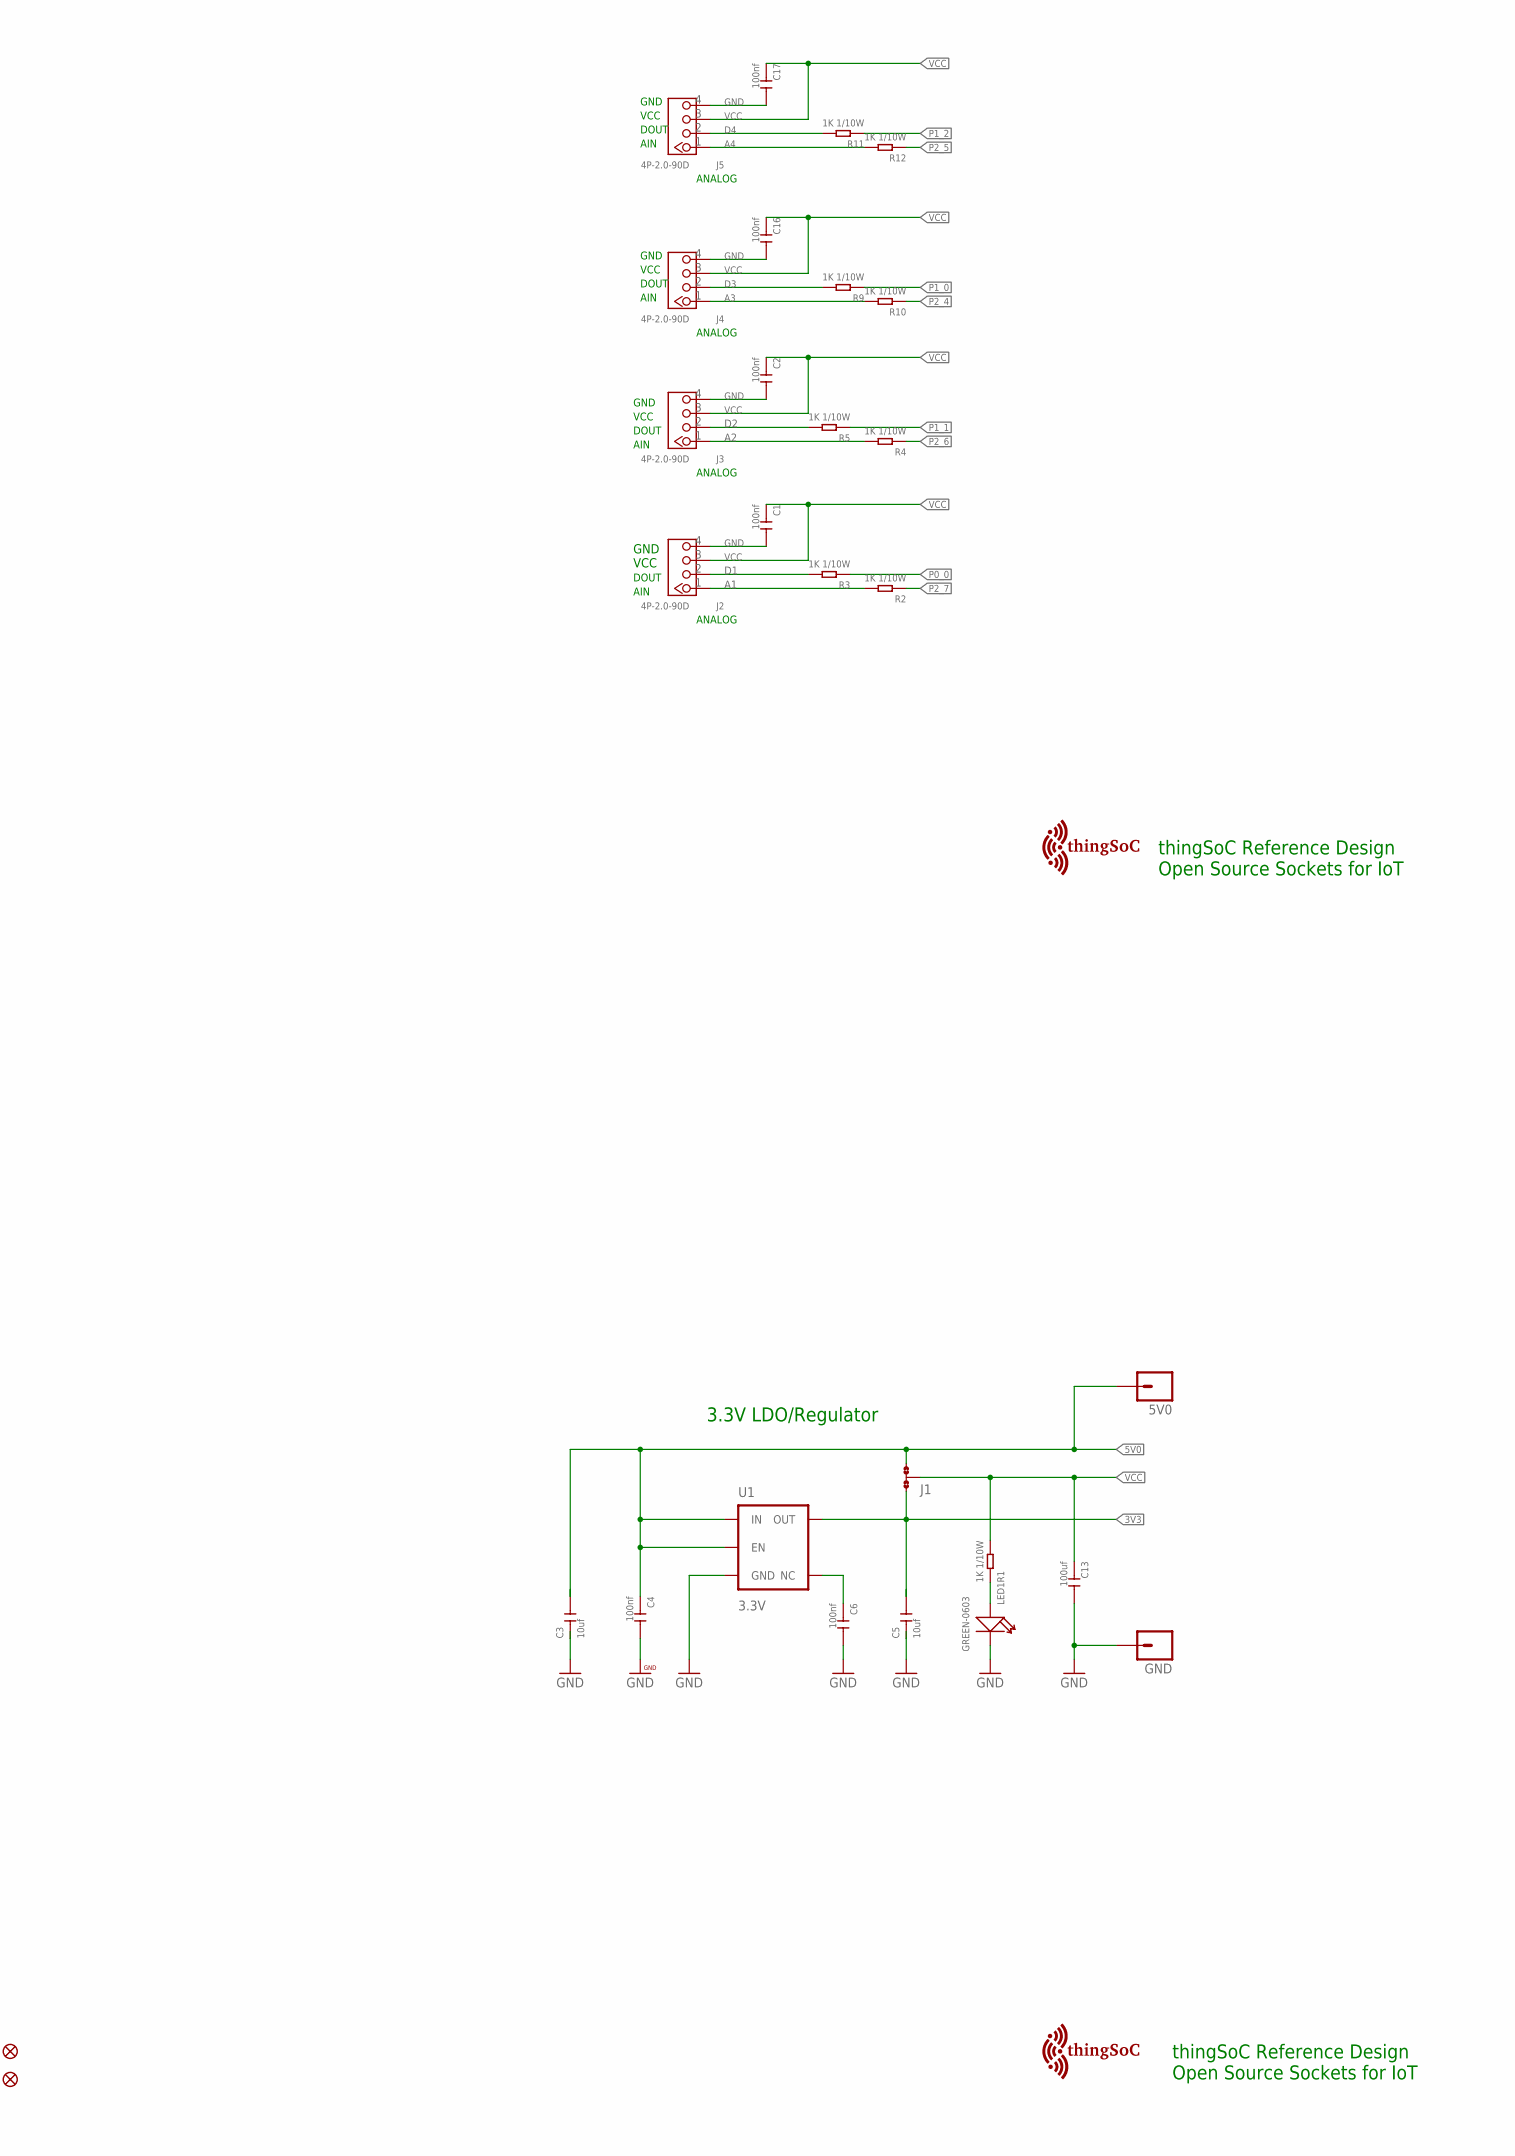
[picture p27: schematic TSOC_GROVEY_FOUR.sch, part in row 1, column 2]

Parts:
5V0: M01PTH; 1X01
$$U$1: TSOC-PCB-SINGLE; TSOC-BB-BRD-DIM
C1, C2, C4, C6, C7, C11, C15, C16, C17: 100nf; C0603
C3, C5: 10uf; C0603
C8: 2.2nf; C0603
C9: 10nf; C0603
C10, C12, C14: 1uF; C0603
C13: 100uf; C1206
FID1, FID2, FID3, FID4: FIDUCIALUFIDUCIAL; MICRO-FIDUCIAL
FTDI: 6p-2.54; H6-2.54
GND: M01PTH; 1X01
J1: NO; JMP-3-NO-PTH-2.54
J2, J3, J4, J5: 4P-2.0-90D; HW4-2.0-90D
JTAG: JTAG-ISSPMIN; PSOC_JTAG_MINSILK
L1, L2: 120OHM-500MA; L0603
LED1: GREEN-0603; LED-0603
LED2: YELLOW-0603; LED-0603
R1, R2, R3, R4, R5, R9, R10, R11, R12, R13: 1K 1/10W; R0603
R6, R7, R8: 10K 1/10W; R0603
TSOC: TSOC-24-BB; TSOC-BB-S24
U1: 3.3V; SOT23-5
U2: CY8C4XXX-28; SSOP28
U$1, U$102: TSOC-LOGO-SMALL; TSOC-LOGO-SML
U$4: TSOC-LOGO; TSOC-LOGO-BLANK
U$101: TSOC-LOGO-LRG

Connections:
3V3: C5.2, J1.1, L2.1, U1.5 (OUT)
5V0: 5V0.1, C3.2, C4.1, J1.3, L1.1, U1.1 (IN), U1.3 (EN)
!URST: C7.1, FTDI.6
!XRES: C7.2, JTAG.3, R7.1, U2.25 (!XRES)
A1: J2.1, R2.2
A2: J3.1, R4.2
A3: J4.1, R10.2
A4: J5.1, R12.2
D1: J2.2, R3.2
D2: J3.2, R5.2
D3: J4.2, R9.2
D4: J5.2, R11.2
GND: C1.2, C2.2, C3.1, C4.2, C5.1, C6.2, C8.1, C9.1, C10.1, C11.1, C12.1, C13.2, C14.1, C15.1, C16.2, C17.2, FTDI.1, FTDI.2, GND.1, J2.4, J3.4, J4.4, J5.4, JTAG.2, LED1.-, TSOC.12B (GND), TSOC.12C (AGND), U1.2 (GND), U2.28 (VSS)
LED1: LED1.+, R1.1
LED2: LED2.-, R13.1
unnamed: C6.1, U1.4 (NC)
P0_0: R3.1, TSOC.6C (!CTS), U2.19 (P0_0)
P0_1: TSOC.5C (!RTS), U2.20 (P0_1)
P0_2: TSOC.4C (!DTR), U2.21 (P0_2)
P0_3: TSOC.3C (!DSR), U2.22 (P0_3)
P0_6: TSOC.2C (!DCD), U2.23 (P0_6)
P0_7: TSOC.1C (!RI), U2.24 (P0_7)
P1_0: R9.1, U2.1 (P1_0)
P1_1: R5.1, U2.2 (P1_1)
P1_2: R11.1, R13.2, U2.3 (P1_2)
P1_7: C11.2, C12.2, U2.4 (P1_7)
P2_2: TSOC.5B (!IRQ), U2.5 (P2_2)
P2_3: TSOC.6B (!ATN), U2.6 (P2_3)
P2_4: R10.1, U2.7 (P2_4)
P2_5: R12.1, U2.8 (P2_5)
P2_6: R4.1, U2.9 (P2_6)
P2_7: R2.1, U2.10 (P2_7)
P3_0: R8.1, TSOC.9C (SCL), U2.11 (P3_0)
P3_1: R6.1, TSOC.10C (SDA), U2.12 (P3_1)
P3_2: JTAG.5, U2.13 (P3_2)
P3_3: JTAG.4, U2.14 (P3_3)
P4_0: FTDI.4, TSOC.8C (TXD), U2.15 (P4_0)
P4_1: FTDI.5, TSOC.7C (RXD), U2.16 (P4_1)
P4_2: C8.2, U2.17 (P4_2)
P4_3: C9.2, U2.18 (P4_3)
TSOC_3V3: L2.2, TSOC.11B (3V3)
TSOC_5V0: L1.2, TSOC.11C (5V0)
VCC: C1.1, C2.1, C13.1, C14.2, C15.2, C16.1, C17.1, FTDI.3, J1.2, J2.3, J3.3, J4.3, J5.3, JTAG.1, LED2.+, R1.2, R6.2, R7.2, R8.2, U2.27 (VDDD)
VCCD: C10.2, U2.26 (VCCD)

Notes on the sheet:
thingSoC Reference Design Open Source Sockets for IoT
3.3V LDO/Regulator
VCC
GND
Internal/Core Bypass
Mains Bypass
SAR Bypass
DOUT
AIN
FTDI UART
CapSense Tank
Rev 3.1 Notes: 1) Move P2_3 (ADC) to AIO 2) Swap UART TX/RX to match GroveyOne 3) Change U1 to CJ1117B
ANALOG
SLAVE

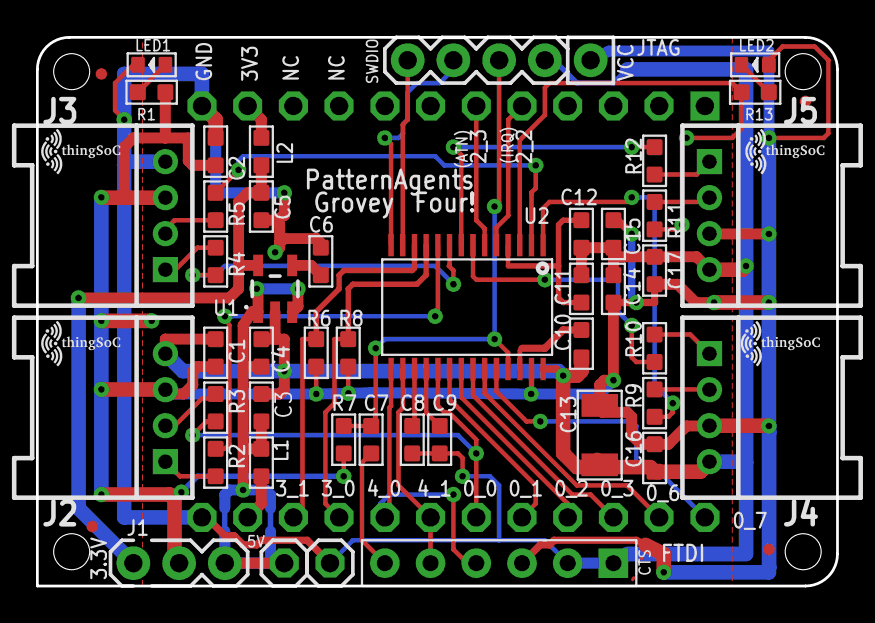
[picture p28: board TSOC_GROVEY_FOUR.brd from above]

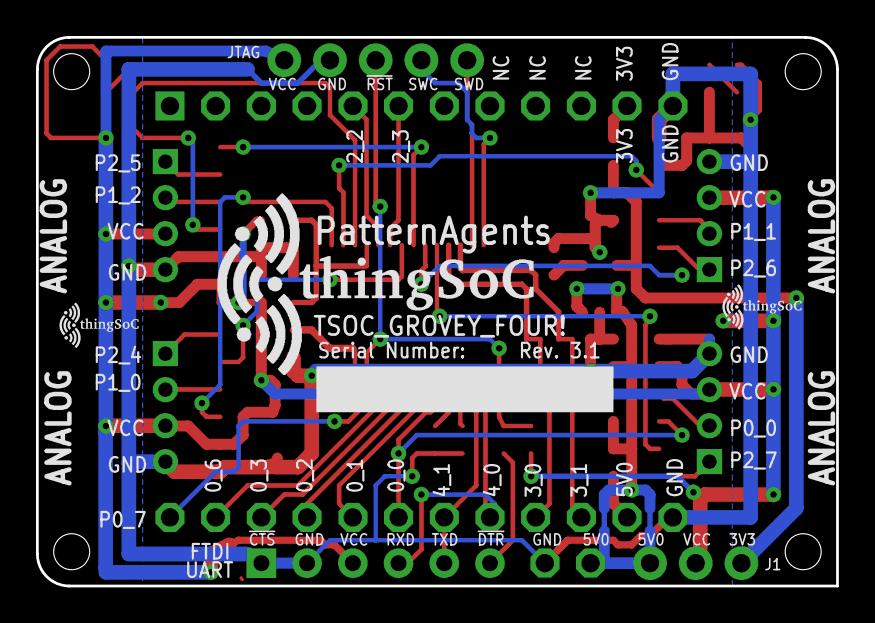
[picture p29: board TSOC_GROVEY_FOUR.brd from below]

Board: 2 copper layers, 44.5 x 30.5 mm, 59 parts (3 on the bottom side), 44 nets.

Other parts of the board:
$$U$2, $$U$3: TSOC-LOGO-SMALL; TSOC-LOGO-SML
U$3, U$100: TSOC-LOGO-SMALL; TSOC-LOGO-SML

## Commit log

2016-09-02 initial version
    [TSOC_GROVEY_FOUR.brd, TSOC_GROVEY_FOUR.sch]
2016-09-03 add product images
    [TSOC_GROVEY_FOUR.brd, TSOC_GROVEY_FOUR.sch]
2016-10-01 update Rev 3.0
    [TSOC_GROVEY_FOUR.brd, TSOC_GROVEY_FOUR.sch, TSOC_GROVEY_FOUR.skp]
2016-12-10 update to Rev3.1
    [TSOC_GROVEY_FOUR.brd, TSOC_GROVEY_FOUR.sch, TSOC_GROVEY_FOUR.skp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]

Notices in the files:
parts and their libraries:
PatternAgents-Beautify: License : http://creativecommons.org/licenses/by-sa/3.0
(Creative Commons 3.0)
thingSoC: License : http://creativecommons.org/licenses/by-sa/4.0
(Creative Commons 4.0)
